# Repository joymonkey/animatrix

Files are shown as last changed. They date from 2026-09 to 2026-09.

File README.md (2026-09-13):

# animatrix

**animatrix** is an open-source hardware, firmware, and software toolkit for custom LED matrix displays.

The project began as a reproduction display for a Daft Punk helmet visor (a 40×3 matrix sitting across the visor opening), but is designed to be hardware- and geometry-agnostic over time to support a variety of custom LED matrix projects.

## Hardware
KiCad design files for the custom flexible PCB LED matrix
- **EDA Tool:** KiCad 10
- **Matrix:** 40 columns × 3 rows (120 LEDs total) on a 2-layer flexible printed circuit (FPC).
- **LEDs:** Standard 3mm (T-1) through-hole LEDs spaced on a 6.0 mm grid pitch.
- **Driver:** Lumissil / ISSI **IS31FL3731**, communicating over I2C with per-pixel 8-bit PWM brightness control.
- **Interface:** Controller tail designed to mate directly with a Waveshare ESP32-S3 Zero.

## Firmware
ESP32-S3 firmware to drive the matrix and play animations
- **Platform:** ESP32-S3 using PlatformIO and the Arduino core.
- **Architecture:**
  - **Core 0 (Networking & Control):** Wi-Fi (SoftAP/Station), AsyncWebServer, REST API, and LittleFS file management.
  - **Core 1 (Animation Engine):** Real-time frame playback and I2C communication with the IS31FL3731 driver.
- **Animation Format:** Interprets lightweight JSON animation files.
- **UI & Control Options:**
  - **Web UI:** Hosted onboard over Wi-Fi (SoftAP/Station) for smartphone/browser control, animation triggering, and file uploads.
  - **Physical Triggers:** Support for external hardware pushbuttons (e.g., wearable/costume triggers), directly wired on via a separate device using ESP-Now.

## Website
Animatrix LED Studio companion web app for creating animations. Preview it at https://joymonkey.github.io/animatrix/
  - Visual editor with frame-by-frame drawing tools and LED bloom/visor simulation.
  - Multi-frame timeline sequencer with undo/redo and variable frame rates.
  - Procedural generators: Cylon/KITT sweeps, robotic eye gestures, audio spectrum visualizers, breathing pulses, and text marquees. All of which can be mixed together into single animations.
  - Multi-track timeline compositing (additive, max, overwrite, and screen blend modes).
  - Export to JSON, C++ PROGMEM headers (Arduino / ESP-IDF), or direct over-the-air HTTP upload to the ESP32-S3.

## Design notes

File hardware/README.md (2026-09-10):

# animatrix — Hardware

This directory contains KiCad 10 design files for a custom 40×3 (120 LEDs total) flexible circuit board (FPC) using standard 3mm through-hole LEDs spaced on a 6.0 mm grid. The display is driven by a Lumissil IS31FL3731 charlieplexing driver IC (SSOP-28) over I2C with individual 8-bit PWM brightness control, powered via 5V USB VBUS, and featuring a direct-solder controller tail designed to interface with a Waveshare ESP32-S3 Zero.

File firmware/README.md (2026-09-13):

# animatrix — Firmware

This directory contains firmware for the animatrix display system targeting the Waveshare ESP32-S3 Zero.

## Project Structure
- **`animatrix/` (Active / Production Release)**: The main release firmware for ESP32-S3. Built with PlatformIO, it features:
  - Multi-matrix hardware abstraction supporting both the **Adafruit 16×9 Charlieplexed Matrix (Product #2947)** and the **Custom 40×3 Daft Punk Visor Matrix** (selectable in `include/config.h`).
  - Native playback engine for `animatrix-v2` JSON animation files exported from the Animatrix Web Studio (flat hex byte streaming, resolution-agnostic headers, loop modes: `infinite`, `once`, `ping_pong`).
  - Dual-Core FreeRTOS division: Core 1 dedicated to high-precision matrix rendering, Core 0 handling Wi-Fi SoftAP (`Animatrix-Visor`), LittleFS storage, and asynchronous REST/upload API with CORS support (`EspUploader.js`).
  - Embedded Cyberpunk HUD web dashboard stored in LittleFS for browser control and drag-and-drop animation deployment.
- **`ledMatrix_prod/` (Reference / Proof of Concept)**: The original proof-of-concept dual-core firmware.
- **`ledMatrix_demo/` (Reference)**: Standalone Arduino demonstration sketch with Charlieplex LUT mapping.

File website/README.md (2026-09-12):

# animatrix // LED Studio & JSON Spec

A flexible, web-based animation suite designed for crafting, sequencing, previewing, and deploying animations to custom LED matrices.

Designed for an **8-bit PWM matrix** (such as a 40×3 120-LED display) powered by an **ESP32-S3** or any other microcontroller. All coordinate mapping is handled cleanly at the firmware driver level.

---

## Quick Start

1. Open `index.html` directly in your browser (no build steps or dependencies needed).
2. The studio initializes with the iconic **Cylon / Knight Rider Visor Sweep** animation pre-loaded.
3. Press `Space` to start/pause playback.
4. Click **Text Marquee** in the header to convert any phrase (e.g. "DAFT PUNK", "ROBOT ROCK") into a scrolling ticker across the 3-row display using the built-in micro font.
5. Click **Push to Display** in the Export/Import section to push animations directly to your ESP32-S3 over WiFi!

---

## Studio Features

- **LED Matrix Simulation**:
  - High-intensity phosphor glow, hot center cores, and bloom.
  - Optional **Visor Glass filter** toggle to simulate looking through tinted smoke acrylic with subtle horizontal scanlines.
  - Optional **Center Axis** center guide (column 20) for dual-eye setups (20×3 Left Eye + 20×3 Right Eye).
- **Comprehensive Drawing Tools**:
  - **Pencil** (brush with 8-bit PWM brightness 0–255).
  - **Eraser** (turn off pixels).
  - **Eyedropper** (sample brightness from any pixel).
  - **Bucket Fill** (flood fill contiguous pixels).
  - **Line Tool** (Bresenham line rasterization).
  - **Hollow & Filled Rectangle** tools.
  - **Nudge & Shift**: Shift frame Left, Right, Up, Down (with edge wrapping).
  - **Flip & Invert**: Flip horizontal/vertical or invert brightness ($255 - b$).
- **Multi-Frame Sequencer & Timeline**:
  - Live miniature canvas thumbnails for every frame.
  - Drag-and-drop frame reordering.
  - Per-frame duration control (e.g., hold eye open for 1200ms, blink for 40ms).
  - Playback loop modes: **Infinite Loop**, **Play Once**, and **Ping-Pong (Bounce)**.
- **Built-in Procedural Generators & Compositing**:
  - **Generators**: Cylon/KITT sweeps (multiple shapes & turnaround endpoints), robotic eye expressions (blink, wink, squint, scan with auto-proportional geometry), 40-band audio spectrum equalizers, sinusoidal breathing pulses, and text marquees.
  - **Multi-Track Compositing**: Target modes (`replace`, `overlay`, `append`) with blend modes (`add`, `max`, `overwrite`, `screen`) and automatic Least Common Multiple (LCM) duration alignment for polyrhythmic layering.
  - **Frame-Count Motion Speed**: Motion speed is synchronized via frames per pass/sweep, keeping layered animations in lockstep with the global timeline FPS.
- **Flexible Matrix Resizing**:
  - Easily reconfigure to any dimension (e.g. 16×9, 24×8, 48×3) via the header configuration modal.

---

## JSON Animation Specification (`animatrix-v1`)

Animations are exported as `.json` files. The specification is designed for minimal parsing overhead and memory footprint on microcontrollers like the ESP32-S3.

### Specification Structure

```json
{
  "$schema": "animatrix-v1",
  "name": "cylon_visor_sweep",
  "author": "Guy-Manuel",
  "version": 1,
  "matrix": {
    "width": 40,
    "height": 3,
    "color": "red",
    "grayscale_depth": 8
  },
  "playback": {
    "fps": 30,
    "loop": "infinite",
    "ping_pong": false
  },
  "total_frames": 10,
  "frames": [
    {
      "duration_ms": 33,
      "encoding": "hex_stream",
      "data": "00ffff00...00"
    }
  ]
}
```

### Encoding Formats Supported

1. **`hex_stream` (Optimized for Microcontrollers)**:
   - Each LED's 8-bit brightness ($0-255$) is represented by two hexadecimal characters (`00` to `ff`).
   - For a $40 \times 3 = 120$ LED matrix, each frame's data string is exactly **240 characters**.
   - Negligible RAM overhead and can be parsed into a raw `uint8_t[120]` buffer with simple byte shifts in C++.
2. **`raw_array` (Human-Readable)**:
   - A 2D array of rows `[[row0_cols...], [row1_cols...], [row2_cols...]]` with integers from 0 to 255.
   - Ideal for inspecting or hand-crafting single frames.

---

## Hardware-Agnostic Matrix Architecture
The studio operates purely with logical $(X, Y)$ coordinates ($0 \le X < \text{width}$, $0 \le Y < \text{height}$) and 8-bit PWM brightness values ($0-255$).

By decoupling the animation tool from specific LED driver hardware:
- **Universal Sequences:** Animation files and C++ tables work with any display technology (Charlieplexed drivers like IS31FL3731, addressable strips like WS2812/NeoPixel, shift-register matrices like MAX7219, or multiplexed HUB75 panels).
- **Firmware Driver Abstraction:** Hardware-specific address translation, pin routing, and Charlieplex LUTs live where they belong—in the microcontroller's `drawPixel(x, y, brightness)` routine.

---

## Firmware Integration & Deployment

Animatrix is designed to connect directly with the ESP32-S3 firmware:

- **Direct Wi-Fi Push:** The studio includes a client-side HTTP uploader (`EspUploader.js`) that sends JSON payloads directly to `POST /api/upload` on the ESP32-S3 over local Wi-Fi.
- **C++ PROGMEM Export:** Export animations directly as compiled C++ byte arrays for embedding into microcontroller flash memory without filesystem dependencies.
- **Microcontroller Processing:** On the ESP32-S3, Core 0 receives and stores the lightweight `hex_stream` data in LittleFS, while Core 1 parses frames and streams them over I2C to the IS31FL3731 driver.

---

## Keyboard Shortcuts

| Key | Action |
| :--- | :--- |
| `Space` | Play / Pause Animation |
| `[` / `]` | Step Backward / Forward one frame |
| `Ctrl + Z` | Undo |
| `Ctrl + Y` | Redo |
| `Ctrl + D` / `Alt + D` | Duplicate Active Frame directly after current |
| `B` | Select Pencil Tool |
| `E` | Select Eraser Tool |
| `I` | Select Eyedropper Tool |
| `G` | Select Bucket Fill Tool |
| `L` | Select Line Tool |
| `R` | Select Rectangle Tool |
| `Shift + Arrow Keys` | Nudge / Shift active frame Left, Right, Up, Down |

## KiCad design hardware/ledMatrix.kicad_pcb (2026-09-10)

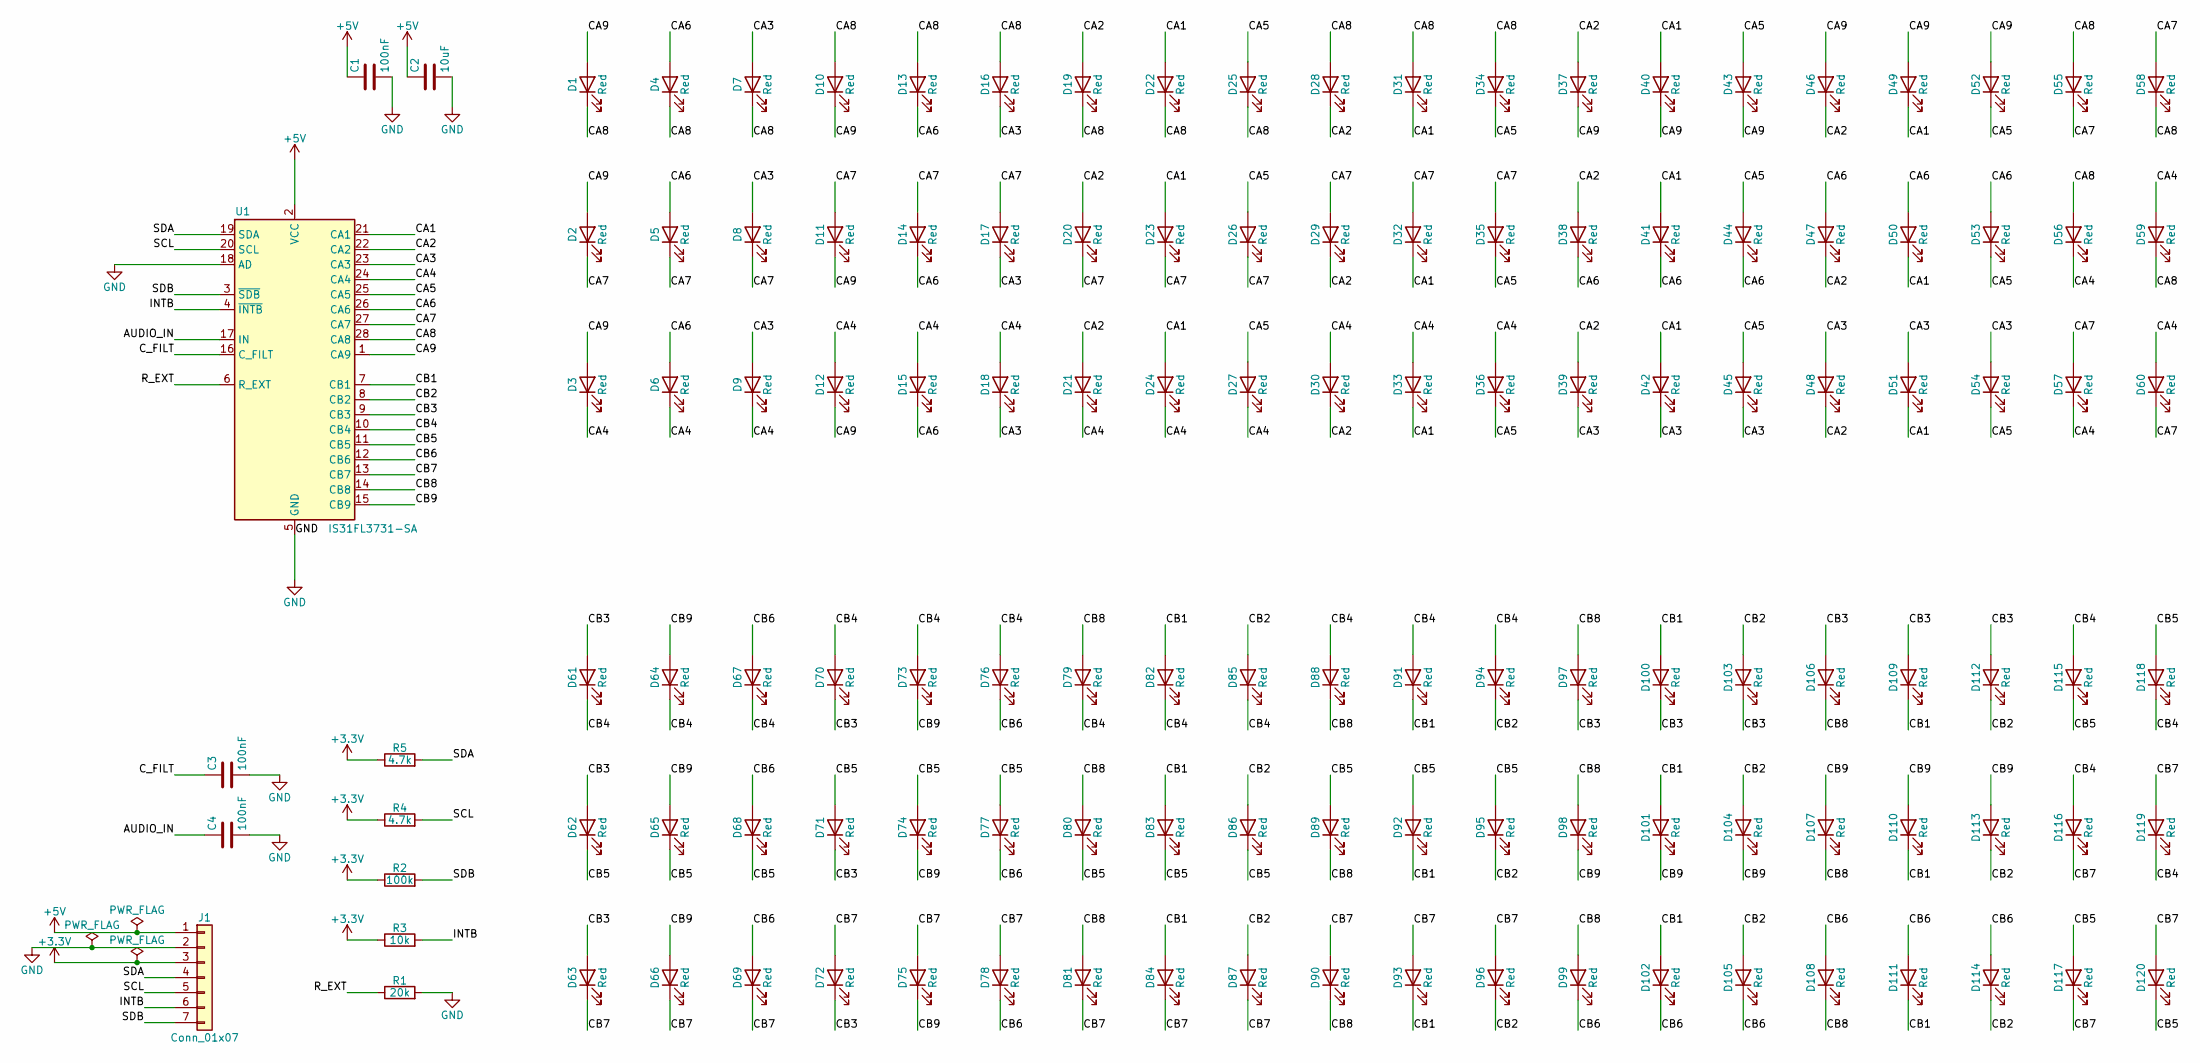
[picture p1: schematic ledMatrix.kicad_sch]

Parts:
C1, C3, C4: 100nF; C_0805_2012Metric
C2: 10uF; C_0805_2012Metric
D1, D2, D3, D4, D5, D6, D7, D8, D9, D10, D11, D12, D13, D14, D15, D16, D17, D18, D19, D20, D21, D22, D23, D24, D25, D26, D27, D28, D29, D30, D31, D32, D33, D34, D35, D36, D37, D38, D39, D40, D41, D42, D43, D44, D45, D46, D47, D48, D49, D50, D51, D52, D53, D54, D55, D56, D57, D58, D59, D60, D61, D62, D63, D64, D65, D66, D67, D68, D69, D70, D71, D72, D73, D74, D75, D76, D77, D78, D79, D80, D81, D82, D83, D84, D85, D86, D87, D88, D89, D90, D91, D92, D93, D94, D95, D96, D97, D98, D99, D100, D101, D102, D103, D104, D105, D106, D107, D108, D109, D110, D111, D112, D113, D114, D115, D116, D117, D118, D119, D120: Red; LED_D3.0mm
J1: Conn_01x07; PinHeader_1x07_P2.54mm_Vertical
R1: 20k; R_0805_2012Metric
R2: 100k; R_0805_2012Metric
R3: 10k; R_0805_2012Metric
R4, R5: 4.7k; R_0805_2012Metric
U1: IS31FL3731-SA; SSOP-28_5.3x10.2mm_P0.65mm

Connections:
+3.3V: J1.3, R2.1, R3.1, R4.1, R5.1
+5V: C1.1, C2.1, J1.1, U1.2 (VCC)
/AUDIO_IN: C4.1, U1.17 (IN)
/CA1: D22.2 (A), D23.2 (A), D24.2 (A), D31.1 (K), D32.1 (K), D33.1 (K), D40.2 (A), D41.2 (A), D42.2 (A), D49.1 (K), D50.1 (K), D51.1 (K), U1.21 (CA1)
/CA2: D19.2 (A), D20.2 (A), D21.2 (A), D28.1 (K), D29.1 (K), D30.1 (K), D37.2 (A), D38.2 (A), D39.2 (A), D46.1 (K), D47.1 (K), D48.1 (K), U1.22 (CA2)
/CA3: D7.2 (A), D8.2 (A), D9.2 (A), D16.1 (K), D17.1 (K), D18.1 (K), D39.1 (K), D42.1 (K), D45.1 (K), D48.2 (A), D51.2 (A), D54.2 (A), U1.23 (CA3)
/CA4: D3.1 (K), D6.1 (K), D9.1 (K), D12.2 (A), D15.2 (A), D18.2 (A), D21.1 (K), D24.1 (K), D27.1 (K), D30.2 (A), D33.2 (A), D36.2 (A), D56.1 (K), D57.1 (K), D59.2 (A), D60.2 (A), U1.24 (CA4)
/CA5: D25.2 (A), D26.2 (A), D27.2 (A), D34.1 (K), D35.1 (K), D36.1 (K), D43.2 (A), D44.2 (A), D45.2 (A), D52.1 (K), D53.1 (K), D54.1 (K), U1.25 (CA5)
/CA6: D4.2 (A), D5.2 (A), D6.2 (A), D13.1 (K), D14.1 (K), D15.1 (K), D38.1 (K), D41.1 (K), D44.1 (K), D47.2 (A), D50.2 (A), D53.2 (A), U1.26 (CA6)
/CA7: D2.1 (K), D5.1 (K), D8.1 (K), D11.2 (A), D14.2 (A), D17.2 (A), D20.1 (K), D23.1 (K), D26.1 (K), D29.2 (A), D32.2 (A), D35.2 (A), D55.1 (K), D57.2 (A), D58.2 (A), D60.1 (K), U1.27 (CA7)
/CA8: D1.1 (K), D4.1 (K), D7.1 (K), D10.2 (A), D13.2 (A), D16.2 (A), D19.1 (K), D22.1 (K), D25.1 (K), D28.2 (A), D31.2 (A), D34.2 (A), D55.2 (A), D56.2 (A), D58.1 (K), D59.1 (K), U1.28 (CA8)
/CA9: D1.2 (A), D2.2 (A), D3.2 (A), D10.1 (K), D11.1 (K), D12.1 (K), D37.1 (K), D40.1 (K), D43.1 (K), D46.2 (A), D49.2 (A), D52.2 (A), U1.1 (CA9)
/CB1: D82.2 (A), D83.2 (A), D84.2 (A), D91.1 (K), D92.1 (K), D93.1 (K), D100.2 (A), D101.2 (A), D102.2 (A), D109.1 (K), D110.1 (K), D111.1 (K), U1.7 (CB1)
/CB2: D85.2 (A), D86.2 (A), D87.2 (A), D94.1 (K), D95.1 (K), D96.1 (K), D103.2 (A), D104.2 (A), D105.2 (A), D112.1 (K), D113.1 (K), D114.1 (K), U1.8 (CB2)
/CB3: D61.2 (A), D62.2 (A), D63.2 (A), D70.1 (K), D71.1 (K), D72.1 (K), D97.1 (K), D100.1 (K), D103.1 (K), D106.2 (A), D109.2 (A), D112.2 (A), U1.9 (CB3)
/CB4: D61.1 (K), D64.1 (K), D67.1 (K), D70.2 (A), D73.2 (A), D76.2 (A), D79.1 (K), D82.1 (K), D85.1 (K), D88.2 (A), D91.2 (A), D94.2 (A), D115.2 (A), D116.2 (A), D118.1 (K), D119.1 (K), U1.10 (CB4)
/CB5: D62.1 (K), D65.1 (K), D68.1 (K), D71.2 (A), D74.2 (A), D77.2 (A), D80.1 (K), D83.1 (K), D86.1 (K), D89.2 (A), D92.2 (A), D95.2 (A), D115.1 (K), D117.2 (A), D118.2 (A), D120.1 (K), U1.11 (CB5)
/CB6: D67.2 (A), D68.2 (A), D69.2 (A), D76.1 (K), D77.1 (K), D78.1 (K), D99.1 (K), D102.1 (K), D105.1 (K), D108.2 (A), D111.2 (A), D114.2 (A), U1.12 (CB6)
/CB7: D63.1 (K), D66.1 (K), D69.1 (K), D72.2 (A), D75.2 (A), D78.2 (A), D81.1 (K), D84.1 (K), D87.1 (K), D90.2 (A), D93.2 (A), D96.2 (A), D116.1 (K), D117.1 (K), D119.2 (A), D120.2 (A), U1.13 (CB7)
/CB8: D79.2 (A), D80.2 (A), D81.2 (A), D88.1 (K), D89.1 (K), D90.1 (K), D97.2 (A), D98.2 (A), D99.2 (A), D106.1 (K), D107.1 (K), D108.1 (K), U1.14 (CB8)
/CB9: D64.2 (A), D65.2 (A), D66.2 (A), D73.1 (K), D74.1 (K), D75.1 (K), D98.1 (K), D101.1 (K), D104.1 (K), D107.2 (A), D110.2 (A), D113.2 (A), U1.15 (CB9)
/C_FILT: C3.1, U1.16 (C_FILT)
/INTB: J1.6, R3.2, U1.4 (~INTB)
/R_EXT: R1.1, U1.6 (R_EXT)
/SCL: J1.5, R4.2, U1.20 (SCL)
/SDA: J1.4, R5.2, U1.19 (SDA)
/SDB: J1.7, R2.2, U1.3 (~SDB)
GND: C1.2, C2.2, C3.2, C4.2, J1.2, R1.2, U1.5 (GND), U1.18 (AD)

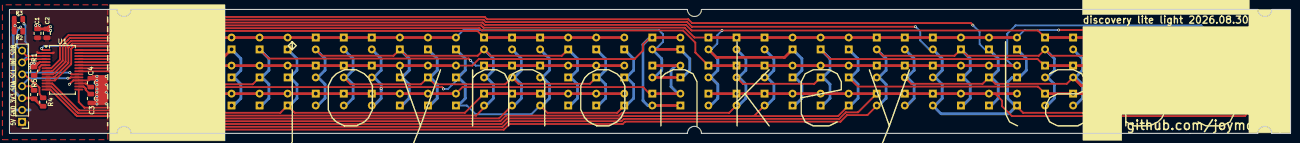
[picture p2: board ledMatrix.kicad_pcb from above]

Board: 2 copper layers, 274.0 x 26.5 mm, 131 parts (0 on the bottom side), 28 nets.

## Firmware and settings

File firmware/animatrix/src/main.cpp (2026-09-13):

#include <Arduino.h>
#include <Wire.h>
#include <WiFi.h>
#include <AsyncTCP.h>
#include <ESPAsyncWebServer.h>
#include <LittleFS.h>
#include <ArduinoJson.h>
#include <Preferences.h>
#include <DNSServer.h>

#include "config.h"
#include "matrix_driver.h"
#include "messages.h"
#include "animation_engine.h"
#include "script_engine.h"
#include "heartbeat.h"

// ==============================================================================
// Shared Global State & Queues
// ==============================================================================
const byte DNS_PORT = 53;
DNSServer dnsServer;
AsyncWebServer server(80);
QueueHandle_t animationQueue = NULL;
SemaphoreHandle_t statusMutex = NULL;

struct SharedStatus {
    bool matrixFound;
    uint8_t i2cAddr;
    char matrixType[24];
    uint16_t matrixWidth;
    uint16_t matrixHeight;
    bool isLoaded;
    bool isPlaying;
    char animName[48];
    uint16_t fps;
    uint32_t totalFrames;
    uint32_t currentFrame;
    char loopMode[16];
} systemStatus;

volatile bool wifiActive = true;
uint32_t lastWifiActivity = 0;
String currentApSsid = AP_SSID;
bool isDefaultSsid = true;

TaskHandle_t TaskCore0;
TaskHandle_t TaskCore1;

// ==============================================================================
// Core 1: Matrix Rendering & Animation Engine Task
// ==============================================================================
void runSwipeTest() {
    int w = displayMatrix->width();
    int h = displayMatrix->height();

    // Horizontal wipe
    for (int x = 0; x < w; x++) {
        displayMatrix->clear();
        for (int y = 0; y < h; y++) {
            displayMatrix->drawPixel(x, y, 255);
        }
        delay(20);
    }
}

void animationTask(void *pvParameters) {
    Serial.println("[Core 1] Animation Task Starting...");

    // Read persisted matrix hardware choice from Preferences (NVS)
    Preferences prefs;
    prefs.begin("animatrix", true);
    String savedMatrix = prefs.getString("matrix_type", "adafruit_16x9");
    prefs.end();
    if (savedMatrix == "custom_3x40") savedMatrix = "custom_40x3";

    setMatrixType(savedMatrix.c_str());

    uint8_t detectedAddr = 0;
    bool matrixOk = initMatrixHardware(detectedAddr);

    if (!matrixOk) {
        Serial.println("[Core 1] ERROR: IS31FL3731 not detected on I2C bus!");
    } else {
        Serial.printf("[Core 1] IS31FL3731 initialized at 0x%02X (%dx%d matrix, type: %s)\n",
                      detectedAddr, displayMatrix->width(), displayMatrix->height(), savedMatrix.c_str());
    }

    // Update shared initial status
    if (xSemaphoreTake(statusMutex, portMAX_DELAY) == pdTRUE) {
        systemStatus.matrixFound = matrixOk;
        systemStatus.i2cAddr = detectedAddr;
        strncpy(systemStatus.matrixType, savedMatrix.c_str(), sizeof(systemStatus.matrixType) - 1);
        systemStatus.matrixWidth = displayMatrix->width();
        systemStatus.matrixHeight = displayMatrix->height();
        systemStatus.isLoaded = false;
        systemStatus.isPlaying = false;
        strncpy(systemStatus.animName, "none", sizeof(systemStatus.animName) - 1);
        systemStatus.fps = 0;
        systemStatus.totalFrames = 0;
        systemStatus.currentFrame = 0;
        strncpy(systemStatus.loopMode, "infinite", sizeof(systemStatus.loopMode) - 1);
        xSemaphoreGive(statusMutex);
    }

    AnimationEngine engine;
    ScriptEngine scriptEngine;

    // Check for matrix-specific startup script or generic startup script
    String startupScript = "";
    String matrixScript = (savedMatrix == "custom_40x3" || savedMatrix == "custom_3x40") ? "/startup_40x3.json" : "/startup_16x9.json";

    if (LittleFS.exists(matrixScript)) {
        startupScript = matrixScript;
    } else if (LittleFS.exists("/startup.json")) {
        startupScript = "/startup.json";
    }

    if (startupScript.length() > 0) {
        scriptEngine.loadScript(startupScript.c_str(), engine);
    } else if (LittleFS.exists(ACTIVE_ANIM_FILE)) {
        engine.loadAnimation(ACTIVE_ANIM_FILE);
    } else {
        // Initial state if no startup script or active animation present: All LEDs on test pattern
        displayMatrix->fillScreen(255);
    }

    AnimationTrigger trigger;
    uint32_t lastStatusUpdate = 0;

    while (1) {
        // Check for incoming trigger without blocking animation timing
        if (xQueueReceive(animationQueue, &trigger, 0) == pdTRUE) {
            Serial.printf("[Core 1] Received Trigger: %d\n", trigger.type);

            // Any user trigger terminates active startup choreography script
            if (scriptEngine.isActive()) {
                scriptEngine.stop();
            }

            switch (trigger.type) {
                case TRIGGER_ALL_ON:
                    engine.stop();
                    displayMatrix->fillScreen(255);
                    break;

                case TRIGGER_ALL_OFF:
                    engine.stop();
                    displayMatrix->clear();
                    break;

                case TRIGGER_TEST_SWIPE: {
                    bool wasLoaded = engine.isLoaded();
                    bool wasPlaying = engine.isPlaying();
                    engine.pause();

                    // Set playing status so heartbeat LED includes yellow in its cycle
                    if (xSemaphoreTake(statusMutex, portMAX_DELAY) == pdTRUE) {
                        systemStatus.isPlaying = true;
                        xSemaphoreGive(statusMutex);
                    }

                    runSwipeTest();

                    if (wasLoaded && wasPlaying) {
                        engine.resume();
                    } else {
                        // Return to default state: all LEDs on at 255
                        displayMatrix->fillScreen(255);
                    }

                    if (xSemaphoreTake(statusMutex, portMAX_DELAY) == pdTRUE) {
                        systemStatus.isPlaying = engine.isPlaying();
                        xSemaphoreGive(statusMutex);
                    }
                    break;
                }

                case TRIGGER_PLAY_SCRIPT:
                    engine.loadAnimation(trigger.scriptFilename);
                    break;

                case TRIGGER_PAUSE:
                    engine.pause();
                    break;

                case TRIGGER_RESUME:
                    engine.resume();
                    break;

                case TRIGGER_SET_MATRIX: {
                    engine.stop();
                    setMatrixType(trigger.scriptFilename);

                    uint8_t detectedAddr = 0;
                    bool matrixOk = initMatrixHardware(detectedAddr);
                    displayMatrix->fillScreen(255); // Reset to default all-on state

                    // Persist to NVS Preferences across reboots
                    Preferences p;
                    p.begin("animatrix", false);
                    p.putString("matrix_type", trigger.scriptFilename);
                    p.end();

                    if (xSemaphoreTake(statusMutex, portMAX_DELAY) == pdTRUE) {
                        systemStatus.matrixFound = matrixOk;
                        systemStatus.i2cAddr = detectedAddr;
                        strncpy(systemStatus.matrixType, trigger.scriptFilename, sizeof(systemStatus.matrixType) - 1);
                        systemStatus.matrixWidth = displayMatrix->width();
                        systemStatus.matrixHeight = displayMatrix->height();
                        systemStatus.isLoaded = false;
                        systemStatus.isPlaying = false;
                        strncpy(systemStatus.animName, "none", sizeof(systemStatus.animName) - 1);
                        xSemaphoreGive(statusMutex);
                    }
                    Serial.printf("[Core 1] Switched matrix target to %s (%dx%d, I2C: 0x%02X)\n",
                                  trigger.scriptFilename, displayMatrix->width(), displayMatrix->height(), detectedAddr);
                    break;
                }

                default:
                    break;
            }
        }

        // Advance script choreography if active, otherwise advance standalone animation
        if (scriptEngine.isActive()) {
            scriptEngine.update(engine);
        } else {
            engine.update();
        }

        // Periodically sync status with Core 0 (every 100ms)
        uint32_t now = millis();
        if (now - lastStatusUpdate > 100) {
            lastStatusUpdate = now;
            if (xSemaphoreTake(statusMutex, 0) == pdTRUE) {
                systemStatus.isLoaded = engine.isLoaded();
                systemStatus.isPlaying = engine.isPlaying();
                strncpy(systemStatus.animName, engine.getName(), sizeof(systemStatus.animName) - 1);
                systemStatus.fps = engine.getFps();
                systemStatus.totalFrames = engine.getTotalFrames();
                systemStatus.currentFrame = engine.getCurrentFrame();
                strncpy(systemStatus.loopMode, engine.getLoopModeStr(), sizeof(systemStatus.loopMode) - 1);
                xSemaphoreGive(statusMutex);
            }
        }

        // Small yield for FreeRTOS tick
        vTaskDelay(2 / portTICK_PERIOD_MS);
    }
}

// ==============================================================================
// Core 0: Network, LittleFS & Web Server Task
// ==============================================================================
void IRAM_ATTR bootButtonISR() {
    static uint32_t lastIsrTime = 0;
    uint32_t currentTime = millis();
    if (currentTime - lastIsrTime > 250) { // 250ms debounce
        AnimationTrigger t = {TRIGGER_TEST_SWIPE, ""};
        xQueueSendFromISR(animationQueue, &t, NULL);
        lastWifiActivity = currentTime;
        lastIsrTime = currentTime;
    }
}

// Helper to inspect animation JSON header (matrix width, height, and title)
// Returns false if file is a script or non-animation file
static bool extractAnimationMeta(File& file, const String& filename, uint16_t& width, uint16_t& height, String& title) {
    width = 0;
    height = 0;
    title = filename;

    // Filter out system scripts from the animation picker
    if (filename.startsWith("startup") || filename.startsWith("script")) {
        return false;
    }

    // 1. Fast filename pattern extraction (e.g. cylon_40x3.json -> 40, 3)
    int xPos = filename.lastIndexOf('x');
    if (xPos > 0 && xPos < filename.length() - 1) {
        int startW = xPos - 1;
        while (startW >= 0 && isDigit(filename[startW])) startW--;
        startW++;
        int endH = xPos + 1;
        while (endH < filename.length() && isDigit(filename[endH])) endH++;
        if (startW < xPos && endH > xPos + 1) {
            width = filename.substring(startW, xPos).toInt();
            height = filename.substring(xPos + 1, endH).toInt();
        }
    }

    // 2. Read first 512 bytes to extract JSON metadata (name, width, height)
    char buf[512];
    file.seek(0);
    size_t bytesRead = file.readBytes(buf, sizeof(buf) - 1);
    buf[bytesRead] = '\0';

    // If file is a script (e.g. animatrix-script-v1 or has "steps":), ignore from animation dropdown
    if (strstr(buf, "\"steps\"") != NULL || strstr(buf, "animatrix-script-v1") != NULL) {
        return false;
    }

    // Find "name": "..."
    const char* pName = strstr(buf, "\"name\"");
    if (pName) {
        const char* q1 = strchr(pName + 6, '\"');
        if (q1) {
            const char* q2 = strchr(q1 + 1, '\"');
            if (q2 && (q2 - q1 < 64)) {
                title = String(q1 + 1).substring(0, q2 - q1 - 1);
            }
        }
    }

    // Find "width": ...
    const char* pWidth = strstr(buf, "\"width\"");
    if (pWidth) {
        const char* col = strchr(pWidth + 7, ':');
        if (col) {
            while (*col == ':' || *col == ' ') col++;
            if (isDigit(*col)) {
                width = atoi(col);
            }
        }
    }

    // Find "height": ...
    const char* pHeight = strstr(buf, "\"height\"");
    if (pHeight) {
        const char* col = strchr(pHeight + 8, ':');
        if (col) {
            while (*col == ':' || *col == ' ') col++;
            if (isDigit(*col)) {
                height = atoi(col);
            }
        }
    }

    return true;
}

void setupNetworkAndIO() {
    Serial.println("[Core 0] Network & IO Task Starting...");

    // Mount LittleFS
    if (!LittleFS.begin(true)) {
        Serial.println("[Core 0] ERROR: LittleFS Mount Failed");
    } else {
        Serial.println("[Core 0] LittleFS mounted successfully.");
    }

    // Configure BOOT button
    pinMode(PIN_BOOT_BTN, INPUT_PULLUP);
    attachInterrupt(digitalPinToInterrupt(PIN_BOOT_BTN), bootButtonISR, FALLING);

    // Read persisted AP SSID from Preferences
    Preferences prefs;
    prefs.begin("animatrix", true);
    currentApSsid = prefs.getString("ap_ssid", AP_SSID);
    String apPass = prefs.getString("ap_pass", AP_PASS);
    isDefaultSsid = (currentApSsid == AP_SSID);
    prefs.end();

    // Setup Wi-Fi SoftAP
    WiFi.mode(WIFI_AP_STA);
    WiFi.softAP(currentApSsid.c_str(), apPass.c_str());
    Serial.printf("[Core 0] Wi-Fi SoftAP '%s' ready. IP: %s (Default SSID: %s)\n",
                  currentApSsid.c_str(), WiFi.softAPIP().toString().c_str(), isDefaultSsid ? "YES" : "NO");

    // Start Captive Portal DNS Server (redirects all domains to local IP)
    dnsServer.start(DNS_PORT, "*", WiFi.softAPIP());
    Serial.println("[Core 0] Captive Portal DNS Server started.");

    lastWifiActivity = millis();

    // Configure Global CORS Headers for Web Studio (EspUploader.js)
    DefaultHeaders::Instance().addHeader("Access-Control-Allow-Origin", "*");
    DefaultHeaders::Instance().addHeader("Access-Control-Allow-Methods", "GET, POST, OPTIONS, PUT");
    DefaultHeaders::Instance().addHeader("Access-Control-Allow-Headers", "Content-Type, X-Animation-Name, Authorization");

    // --------------------------------------------------------------------------
    // Captive Portal Detection Routes (iOS, Android, Windows)
    // --------------------------------------------------------------------------
    auto handleCaptiveRedirect = [](AsyncWebServerRequest *request) {
        lastWifiActivity = millis();
        request->redirect("http://" + WiFi.softAPIP().toString() + "/");
    };

    server.on("/hotspot-detect.html", HTTP_GET, handleCaptiveRedirect); // Apple
    server.on("/canonical.html", HTTP_GET, handleCaptiveRedirect);      // Apple
    server.on("/generate_204", HTTP_GET, handleCaptiveRedirect);        // Android
    server.on("/gen_204", HTTP_GET, handleCaptiveRedirect);             // Android

    // Windows NCSI Probes: Spoof success so Windows does NOT launch browser to msftconnecttest.com/redirect (which redirects to msn.com)
    server.on("/connecttest.txt", HTTP_GET, [](AsyncWebServerRequest *request) {
        lastWifiActivity = millis();
        request->send(200, "text/plain", "Microsoft Connect Test");
    });
    server.on("/ncsi.txt", HTTP_GET, [](AsyncWebServerRequest *request) {
        lastWifiActivity = millis();
        request->send(200, "text/plain", "Microsoft NCSI");
    });
    // In case any browser or Windows client still navigates to /redirect
    server.on("/redirect", HTTP_GET, handleCaptiveRedirect);

    // Preflight OPTIONS & Catch-all Captive Portal Redirect Handler
    server.onNotFound([](AsyncWebServerRequest *request) {
        lastWifiActivity = millis();
        if (request->method() == HTTP_OPTIONS) {
            request->send(200);
            return;
        }

        // If client requested an external hostname (e.g. captive.apple.com), redirect to root
        String host = request->host();
        String localIp = WiFi.softAPIP().toString();
        if (!host.equalsIgnoreCase(localIp)) {
            request->redirect("http://" + localIp + "/");
            return;
        }

        request->send(404, "text/plain", "Not Found");
    });

    // --------------------------------------------------------------------------
    // REST API: GET /api/status
    // --------------------------------------------------------------------------
    server.on("/api/status", HTTP_GET, [](AsyncWebServerRequest *request) {
        lastWifiActivity = millis();
        JsonDocument doc;

        if (xSemaphoreTake(statusMutex, portMAX_DELAY) == pdTRUE) {
            doc["status"] = "online";
            JsonObject mat = doc["matrix"].to<JsonObject>();
            mat["found"] = systemStatus.matrixFound;
            mat["i2c_addr"] = systemStatus.i2cAddr;
            mat["type"] = systemStatus.matrixType;
            mat["width"] = systemStatus.matrixWidth;
            mat["height"] = systemStatus.matrixHeight;

            JsonObject anim = doc["animation"].to<JsonObject>();
            anim["loaded"] = systemStatus.isLoaded;
            anim["playing"] = systemStatus.isPlaying;
            anim["name"] = systemStatus.animName;
            anim["fps"] = systemStatus.fps;
            anim["total_frames"] = systemStatus.totalFrames;
            anim["current_frame"] = systemStatus.currentFrame;
            anim["loop"] = systemStatus.loopMode;

            xSemaphoreGive(statusMutex);
        }

        JsonObject sys = doc["system"].to<JsonObject>();
        sys["free_heap"] = ESP.getFreeHeap();
        sys["free_psram"] = ESP.getFreePsram();
        sys["uptime_sec"] = millis() / 1000;

        JsonObject wifi = doc["wifi"].to<JsonObject>();
        wifi["ssid"] = currentApSsid;
        wifi["is_default"] = isDefaultSsid;

        String response;
        serializeJson(doc, response);
        request->send(200, "application/json", response);
    });

    // --------------------------------------------------------------------------
    // REST API: POST /api/upload (Direct JSON upload from Animatrix Web Studio)
    // --------------------------------------------------------------------------
    server.on(
        "/api/upload",
        HTTP_POST,
        [](AsyncWebServerRequest *request) {
            // Completed upload response
            request->send(200, "text/plain", "Animation loaded successfully on helmet!");
        },
        NULL,
        [](AsyncWebServerRequest *request, uint8_t *data, size_t len, size_t index, size_t total) {
            lastWifiActivity = millis();
            static File uploadFile;
            static String uploadPath;

            if (index == 0) {
                uploadPath = ACTIVE_ANIM_FILE;
                if (request->hasHeader("X-Animation-Name")) {
                    String name = request->getHeader("X-Animation-Name")->value();
                    name.trim();
                    if (name.length() > 0) {
                        uploadPath = name.startsWith("/") ? name : "/" + name;
                    }
                }
                uploadFile = LittleFS.open(uploadPath, "w");
                if (!uploadFile) {
                    Serial.println("[Core 0] Error opening animation file for write!");
                    return;
                }
            }

            if (uploadFile) {
                uploadFile.write(data, len);
            }

            if (index + len == total) {
                if (uploadFile) {
                    uploadFile.close();
                    Serial.printf("[Core 0] Direct JSON upload complete: %s (%u bytes)\n", uploadPath.c_str(), (uint32_t)total);

                    // Notify Core 1 to play the newly uploaded animation
                    AnimationTrigger t;
                    t.type = TRIGGER_PLAY_SCRIPT;
                    strncpy(t.scriptFilename, uploadPath.c_str(), sizeof(t.scriptFilename) - 1);
                    xQueueSend(animationQueue, &t, 0);
                }
            }
        }
    );

    // --------------------------------------------------------------------------
    // REST API: POST /api/trigger (Actions: all_on, all_off, test, play, pause)
    // --------------------------------------------------------------------------
    server.on("/api/trigger", HTTP_POST, [](AsyncWebServerRequest *request) {
        lastWifiActivity = millis();
        AnimationTrigger t = {TRIGGER_NONE, ""};

        if (request->hasParam("action", true)) {
            String act = request->getParam("action", true)->value();
            if (act == "all_on") t.type = TRIGGER_ALL_ON;
            else if (act == "all_off") t.type = TRIGGER_ALL_OFF;
            else if (act == "test") t.type = TRIGGER_TEST_SWIPE;
            else if (act == "pause") t.type = TRIGGER_PAUSE;
            else if (act == "resume") t.type = TRIGGER_RESUME;
            else if (act == "play") {
                t.type = TRIGGER_PLAY_SCRIPT;
                String targetFile = ACTIVE_ANIM_FILE;
                if (request->hasParam("file", true)) {
                    targetFile = request->getParam("file", true)->value();
                } else if (request->hasParam("file")) {
                    targetFile = request->getParam("file")->value();
                }
                if (!targetFile.startsWith("/")) targetFile = "/" + targetFile;
                strncpy(t.scriptFilename, targetFile.c_str(), sizeof(t.scriptFilename) - 1);
            }
        }

        if (t.type != TRIGGER_NONE) {
            xQueueSend(animationQueue, &t, 0);
            request->send(200, "text/plain", "Action executed.");
        } else {
            request->send(400, "text/plain", "Invalid or missing action parameter.");
        }
    });
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
void loop() {
    static bool isPlaying = false;
    if (xSemaphoreTake(statusMutex, 0) == pdTRUE) {
        isPlaying = systemStatus.isPlaying;
        xSemaphoreGive(statusMutex);
    }

    HeartbeatIndicator::update(isPlaying, wifiActive);
    vTaskDelay(50 / portTICK_PERIOD_MS);
}

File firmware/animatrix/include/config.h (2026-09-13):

#ifndef CONFIG_H
#define CONFIG_H

#include <Arduino.h>

// ==============================================================================
// 1. Hardware Matrix Selection
// ==============================================================================
#define MATRIX_TYPE_ADAFRUIT_16X9 1  // Adafruit 16x9 Charlieplexed Matrix (#2947)
#define MATRIX_TYPE_CUSTOM_40X3   2  // Custom 40x3 Daft Punk Visor Flex Matrix
#define MATRIX_TYPE_CUSTOM_3X40   MATRIX_TYPE_CUSTOM_40X3 // Compatibility alias

// Set your active matrix geometry here:
#ifndef ACTIVE_MATRIX_TYPE
#define ACTIVE_MATRIX_TYPE MATRIX_TYPE_ADAFRUIT_16X9
#endif

// ==============================================================================
// 2. Pin Definitions (Waveshare ESP32-S3 Zero)
// ==============================================================================
#define PIN_I2C_SDA     1
#define PIN_I2C_SCL     2
#define PIN_INTB        3   // Driver interrupt pin
#define PIN_SDB         4   // Driver active-low shutdown pin
#define PIN_BOOT_BTN    0   // Onboard BOOT button
#define PIN_RGB_LED     21  // Onboard WS2812 RGB NeoPixel

// ==============================================================================
// 3. Heartbeat Indicator Settings
// ==============================================================================
#define HEARTBEAT_BRIGHTNESS    3    // Low brightness (~3/255)
#define HEARTBEAT_BLINK_MS      800  // Slow blink phase interval (800ms each state: Green -> Blue -> Yellow)

// ==============================================================================
// 4. I2C Bus & IS31FL3731 Settings
// ==============================================================================
#define I2C_BUS_SPEED       400000  // 400kHz Fast Mode
#define IS31_ADDR_PRIMARY   0x74    // Default for Adafruit breakout
#define IS31_ADDR_SECONDARY 0x75    // Default for Visor flex (AD pulled high)

// ==============================================================================
// 5. Wi-Fi SoftAP & Inactivity Settings
// ==============================================================================
#define AP_SSID             "Animatrix-Visor"
#define AP_PASS             "daftpunk"
#define WIFI_TIMEOUT_MS     (3 * 60 * 1000) // 3 minutes inactivity timeout

// ==============================================================================
// 6. Filesystem & Animation File Paths
// ==============================================================================
#define ACTIVE_ANIM_FILE    "/active_anim.json"
#define DEFAULT_ANIM_FILE   "/default_anim.json"

#endif // CONFIG_H

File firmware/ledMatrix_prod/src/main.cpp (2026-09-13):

#include <Arduino.h>
#include <Wire.h>
#include <WiFi.h>
#include <AsyncTCP.h>
#include <ESPAsyncWebServer.h>
#include <LittleFS.h>
#include <esp_now.h>
#include <ArduinoJson.h>

#include "matrix_driver.h"
#include "messages.h"
#include "animation_engine.h"

// --- Configuration ---
#define AP_SSID "LED-Matrix"
#define AP_PASS "daftpunk"
#define WIFI_TIMEOUT_MS (2 * 60 * 1000) // 2 minutes inactivity timeout

// --- Globals ---
CustomMatrix40x3 matrix;
AsyncWebServer server(80);
QueueHandle_t animationQueue;

bool wifiActive = true;
uint32_t lastWifiActivity = 0;

// --- Task Handles ---
TaskHandle_t TaskCore0;
TaskHandle_t TaskCore1;

// --- Core 1: Animation Task ---
void animationTask(void *pvParameters) {
    Serial.println("[Core 1] Animation Task Started.");

    // Initialize I2C and Matrix
    pinMode(PIN_SDB, OUTPUT);
    digitalWrite(PIN_SDB, HIGH);
    delay(20);

    Wire.begin(PIN_I2C_SDA, PIN_I2C_SCL, 400000);
    uint8_t activeAddr = IS31_I2C_ADDR;
    if (!matrix.begin(activeAddr)) {
        Serial.printf("[Core 1] Matrix not responding at 0x%02X, probing 0x74...\n", activeAddr);
        if (matrix.begin(0x74)) {
            activeAddr = 0x74;
            Serial.println("[Core 1] Matrix found at 0x74!");
        } else {
            Serial.println("[Core 1] Matrix init failed! Scanning I2C bus...");
            int found = 0;
            for (uint8_t addr = 1; addr < 127; addr++) {
                Wire.beginTransmission(addr);
                if (Wire.endTransmission() == 0) {
                    Serial.printf(" - Found I2C device at 0x%02X\n", addr);
                    found++;
                }
            }
            if (found == 0) {
                Serial.println(" - No I2C devices responded! Check SDA (GPIO1), SCL (GPIO2), VCC, GND, and SDB.");
            }
            while (1) vTaskDelay(100 / portTICK_PERIOD_MS);
        }
    }
    
    Serial.printf("[Core 1] Matrix init success at 0x%02X.\n", activeAddr);
    matrix.clear();
    
    // Initial State: All LEDs ON
    matrix.fillScreen(255); // Full brightness

    AnimationTrigger trigger;

    while (1) {
        if (xQueueReceive(animationQueue, &trigger, 0) == pdTRUE) {
            Serial.printf("[Core 1] Received Trigger: %d\n", trigger.type);
            
            if (trigger.type == TRIGGER_ALL_ON) {
                matrix.fillScreen(255);
            } 
            else if (trigger.type == TRIGGER_ALL_OFF) {
                matrix.clear();
            }
            else if (trigger.type == TRIGGER_TEST_ANIMATION) {
                // Basic swipe test
                for (int x = 0; x < 40; x++) {
                    matrix.clear();
                    matrix.drawLine(x, 0, x, 2, 255);
                    delay(30);
                }
                matrix.fillScreen(255); // Return to all on
            }
            else if (trigger.type == TRIGGER_JSON_SCRIPT) {
                // Execute JSON script from LittleFS
                runJsonAnimation(trigger.scriptFilename);
            }
        }

        // Add a small delay to yield to watchdog and other RTOS tasks
        vTaskDelay(10 / portTICK_PERIOD_MS);
    }
}

// --- Core 0: Network & IO Task ---
void IRAM_ATTR bootButtonISR() {
    static uint32_t lastIsrTime = 0;
    uint32_t currentTime = millis();
    if (currentTime - lastIsrTime > 200) { // 200ms debounce
        AnimationTrigger t = {TRIGGER_TEST_ANIMATION, ""};
        xQueueSendFromISR(animationQueue, &t, NULL);
        lastWifiActivity = currentTime; // Wake up Wi-Fi logic if we press button? Optional.
        lastIsrTime = currentTime;
    }
}

void setupNetworkAndIO() {
    Serial.println("[Core 0] Network & IO Task Started.");

    // Filesystem
    if (!LittleFS.begin(true)) {
        Serial.println("[Core 0] LittleFS Mount Failed");
    }

    // Button
    pinMode(PIN_BOOT_BTN, INPUT_PULLUP);
    attachInterrupt(digitalPinToInterrupt(PIN_BOOT_BTN), bootButtonISR, FALLING);

    // Wi-Fi SoftAP
    WiFi.mode(WIFI_AP_STA); // We need STA mode enabled temporarily to init ESP-NOW sometimes, but AP is main
    WiFi.softAP(AP_SSID, AP_PASS);
    Serial.print("[Core 0] AP IP address: ");
    Serial.println(WiFi.softAPIP());
    
    lastWifiActivity = millis();

    // Web Server setup
    server.on("/", HTTP_GET, [](AsyncWebServerRequest *request){
        lastWifiActivity = millis();
        request->send(LittleFS, "/index.html", "text/html");
    });
    
    server.on("/style.css", HTTP_GET, [](AsyncWebServerRequest *request){
        lastWifiActivity = millis();
        request->send(LittleFS, "/style.css", "text/css");
    });

    server.on("/script.js", HTTP_GET, [](AsyncWebServerRequest *request){
        lastWifiActivity = millis();
        request->send(LittleFS, "/script.js", "application/javascript");
    });

    server.on("/trigger", HTTP_POST, [](AsyncWebServerRequest *request){
        lastWifiActivity = millis();
        if (request->hasParam("type", true)) {
            String typeStr = request->getParam("type", true)->value();
            AnimationTrigger t;
            if (typeStr == "all_on") t.type = TRIGGER_ALL_ON;
            else if (typeStr == "all_off") t.type = TRIGGER_ALL_OFF;
            else if (typeStr == "test") t.type = TRIGGER_TEST_ANIMATION;
            else if (typeStr == "json_script") {
                t.type = TRIGGER_JSON_SCRIPT;
                strncpy(t.scriptFilename, "/uploaded.json", sizeof(t.scriptFilename) - 1);
            }
            else t.type = TRIGGER_NONE;
            
            xQueueSend(animationQueue, &t, 0);
            request->send(200, "text/plain", "Triggered");
        } else {
            request->send(400, "text/plain", "Missing type");
        }
    });

    // File upload handler
    server.on("/upload", HTTP_POST, [](AsyncWebServerRequest *request) {
        request->send(200, "text/plain", "Upload Complete");
    }, [](AsyncWebServerRequest *request, const String& filename, size_t index, uint8_t *data, size_t len, bool final) {
        lastWifiActivity = millis();
        static File uploadFile;
        if (!index) {
            uploadFile = LittleFS.open("/uploaded.json", "w");
            if (!uploadFile) {
                Serial.println("Failed to open file for writing");
            }
        }
        if (uploadFile) {
            uploadFile.write(data, len);
        }
        if (final) {
            if (uploadFile) {
                uploadFile.close();
                Serial.println("Upload complete: /uploaded.json");
            }
        }
    });

    server.begin();

    // ESP-NOW Stub
    if (esp_now_init() != ESP_OK) {
        Serial.println("[Core 0] Error initializing ESP-NOW");
    } else {
        Serial.println("[Core 0] ESP-NOW initialized.");
        // We will register recv callbacks here later
    }
}
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

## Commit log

2026-09-10 Initial LED Matrix project! Hardware, firmware, web-app, oh my!
    [ledMatrix.kicad_pcb, ledMatrix.kicad_sch]
2026-09-10 Add path filtering so Pages only deploys on website changes
2026-09-11 tweaked pencil tool and PWM selection (now more like the common Photoshop style foreground/background swatch selector)
2026-09-12 website tweaksl updated json schema, changed generators to frame-based vs a mix of frame and timing based
2026-09-12 added timeline tools to add/duplicate frames more intuitively, invert all frames, reverse frame order, delete all
2026-09-12 added random/dice button, initial option to go straight to generators
2026-09-17 added diagnostics to web ui to help with LED matrix assembly, fixed bad cylon-sweep animation for the 40x3 board.
2026-10-04 added firmware update/install feature from the Animatrix LED Studio website
2026-11-05 feat(firmware): audio visualizers, single-binary provisioning, and brightness controls
    - Add I2S microphone (INMP441) DSP processing and auto-detection on startup
    - Add procedural audio visualizers (VU meter, waveform, beat ripple, vad breath)
    - Add single-binary LittleFS self-provisioning on boot with payload hash tracking
    - Add dynamic Git version injection during build and Web UI sync
    - Add configurable maximum brightness limiter with live display preview and UI slider
    - Add hardware BOOT button brightness cycling in 5% steps with bottom-row gauge bar
    - Fix startup sequence fallback and Web UI startup mode synchronization
    - Refresh distribution binaries for website web flashing
